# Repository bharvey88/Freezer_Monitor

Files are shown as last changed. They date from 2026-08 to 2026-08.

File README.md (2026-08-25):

# Freezer Monitor

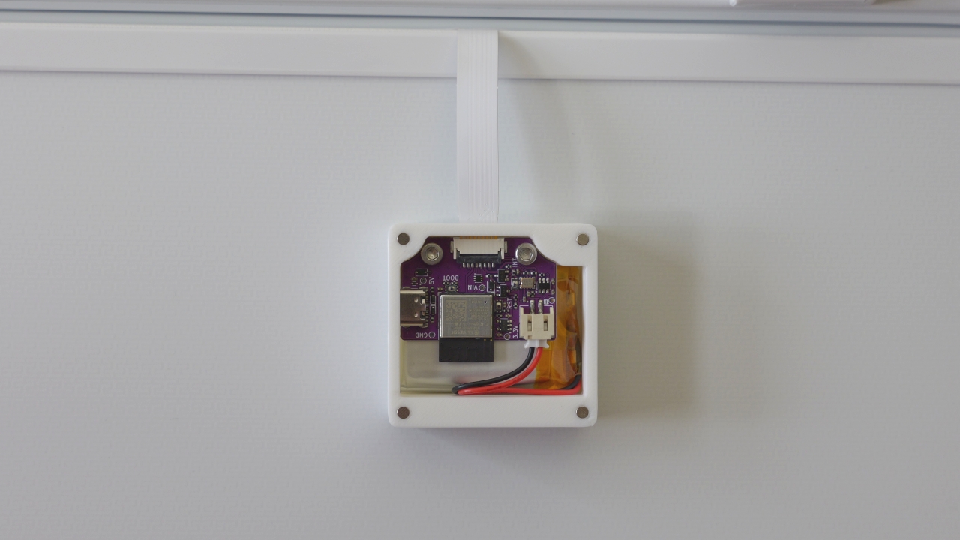
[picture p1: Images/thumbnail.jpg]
thumbnail


Battery-powered freezer monitor for Home Assistant and ESPHome. It continuously watches freezer temperature using a flat printed circuit sensor probe, wakes Home Assistant immediately for high-temperature events, and uses RTC-controlled power cycling for long battery life.

Setup Video: https://youtu.be/nzpPNruYSMk

Technical Video: https://youtu.be/-qzcmOnRHUw

Setting up Helpers and Notifcations: https://youtu.be/nKuBQElTua8

Etsy (purchase): https://www.etsy.com/listing/4555225886/freezer-monitor-for-home-assistant

## Contents

- [Requirements](#requirements)
- [Assemble and charge](#assemble-and-charge)
  - [Replacement battery safety](#replacement-battery-safety)
- [First-time setup](#first-time-setup)
- [How it works](#how-it-works)
  - [Optional persistent Keep Awake helper](#optional-persistent-keep-awake-helper)
- [Device controls and readings](#device-controls-and-readings)
- [Alerts and notifications](#alerts-and-notifications)
  - [Create a phone push or email alert](#create-a-phone-push-or-email-alert)
  - [Optional alert blueprint](#optional-alert-blueprint)
- [Updating and advanced ESPHome use](#updating-and-advanced-esphome-use)
  - [Manual USB flashing](#manual-usb-flashing)
- [Errata](#errata)
- [Project files](#project-files)
- [Troubleshooting](#troubleshooting)

## Requirements

- Home Assistant with the ESPHome add-on or integration installed.
- A 2.4 GHz Wi-Fi network.
- The supplied pre-flashed Freezer Monitor, FPC probe, and battery.
- Optional: Home Assistant Companion App for phone push notifications, or an existing Home Assistant email notification service for email alerts.

## Assemble and charge

1. Connect the temperature probe.
2. Connect the supplied battery.
3. Charge the battery through the USB port.
4. Continue with first-time setup below.

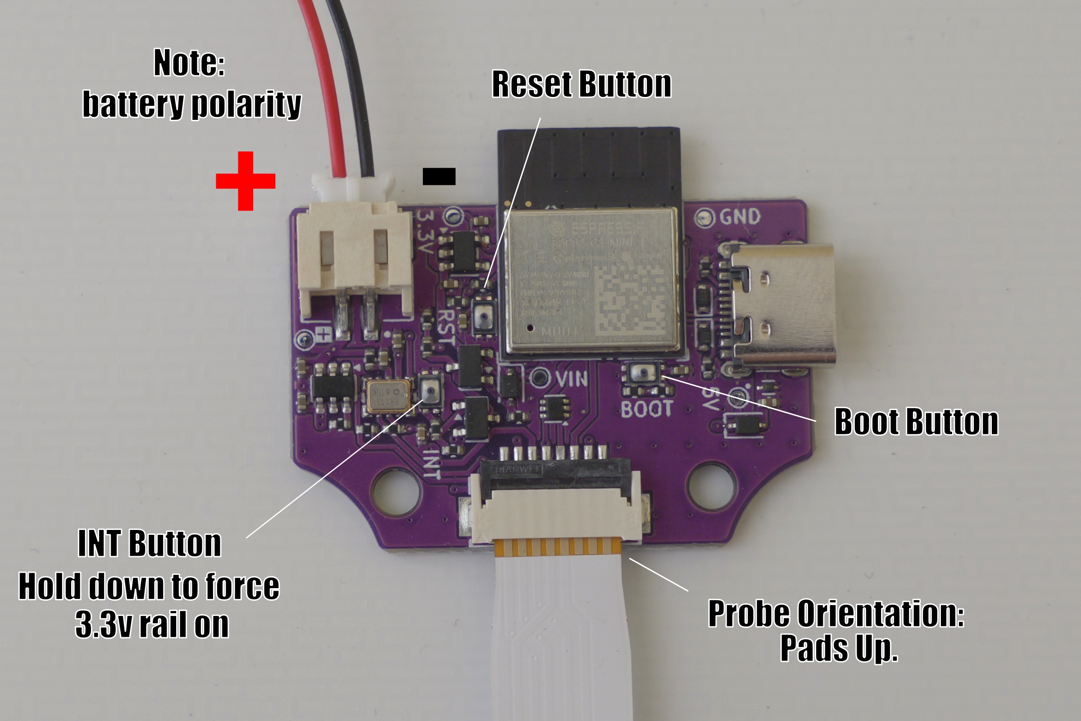
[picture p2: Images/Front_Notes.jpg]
Front view showing probe connection


### Replacement battery safety

Use only a single-cell 3.7 V LiPo battery with a PH-style connector. Verify connector polarity before connecting a replacement battery. Reversed polarity can permanently damage the PCB.

## First-time setup

1. Power the freezer monitor via USB. It stays awake by default for configuration.
2. Provision Wi-Fi using either Bluetooth Improv or the `Freezer Monitor Setup` captive portal. Provisioning has a ten minute timeout. Power cycle the device to reopen the provisioning window if it expires. The fallback `Freezer Monitor Setup` Wi-Fi network is unsecured. Complete provisioning promptly and configure one unprovisioned monitor at a time.
3. Finish Home Assistant discovery and setup by going to **Settings → Devices & services** and adding the freezer monitor. Home Assistant assigns the device API encryption key during this process.
4. Go into the device settings and set alert thresholds and heartbeat schedule if desired.
5. Unplug from USB power and turn off **Keep On for Configuration** in the device controls. Normal low-power monitoring starts after the current wake period. Note: without an initial valid RTC time sync, normal shutdown cycles cannot start, and the device will not power itself off. Once an initial time sync happens, the RTC can maintain time even if it cannot sync every power cycle (such as when wifi is down), so this is only an issue at initial setup.

## How it works

The probe-side TMP102 sensor monitors freezer temperature continuously, even when the ESP32 is powered off. The RTC controls ESP32 power and records both scheduled wakes and temperature events.

| Term | Meaning |
| --- | --- |
| **Alarm** | A scheduled RTC heartbeat wake. Default: every 12 hours. |
| **Event / Alert** | A freezer temperature above **High Temp Threshold**. This wakes the ESP32 immediately. |
| | |

During a normal Alarm wake, the monitor powers on for about 12 seconds, updates Home Assistant with freezer and ambient temperature, battery voltage/percentage, Wi-Fi signal, and wake status, then the RTC cuts ESP32 power again.

The default heartbeat schedule is every 12 hours. **Wake Start Hour (UTC)** and **Wake Start Minute** determine the base heartbeat time; **Wake Interval Hours** selects interval length in between heartbeats. Wake times for the device are then derived from the selected time and interval settings. All schedule times are UTC. Adjust them manually when local-time or daylight-saving changes require it. Setting wake interval to 0 will wake the device once a day (every 24hrs).

The monitor must be awake and connected to Wi-Fi before Home Assistant can update the device settings. Normal wake windows are brief; enable **Keep On for Configuration** while making several changes, updating firmware, or adopting the device.

### Optional persistent Keep Awake helper

The device control **Keep On for Configuration** always remains available and works while the monitor is awake. For an optional control that remembers a request made while the monitor is powered off, create a Home Assistant **Toggle** helper named `Freezer Monitor Keep Awake`. Its entity ID must be `input_boolean.freezer_monitor_keep_awake`.

Use **Settings → Devices & services → Helpers → Create helper → Toggle**. The helper state is stored by Home Assistant. On the monitor's next successful connection to Home Assistant, its saved state is applied: on keeps the monitor awake; off resumes normal RTC power cycling. Using the device's existing **Keep On for Configuration** control also updates the helper when it exists.

You will also need to allow the device to perform actions for the helper to function. Navigate to **Settings → Devices & services → ESPHome** and find the device in the list. Click on the gear to access the options, and check the box for **Allow the device to perform Home Assistant actions.**

The helper cannot power on the monitor immediately and cannot apply its value during a wake where the monitor cannot connect to Home Assistant. Users who do not create the helper can continue using the device control normally during an awake period.

## Device controls and readings

| Home Assistant entity | Purpose |
| --- | --- |
| **CONTROLS**| |
| **Acknowledge Freezer Alarm** | Acknowledges a temperature event so normal power cycling can resume. |
| **Clear Temp Threshold** | Temperature the freezer must fall below before an alert can clear. Default: 9 °F. |
| **High Temp Threshold** | Temperature that triggers an Event/Alert. Default: 10 °F. |
|||
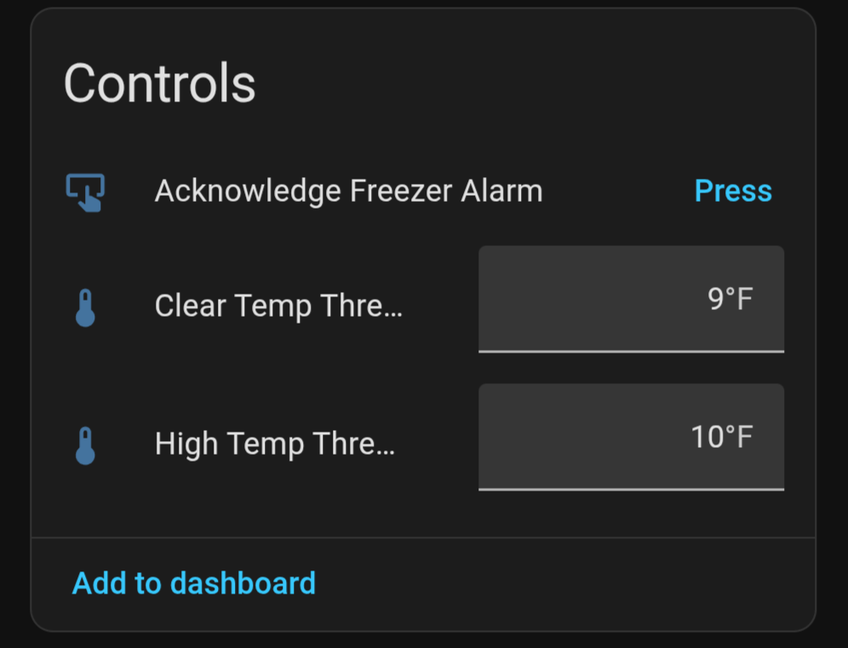
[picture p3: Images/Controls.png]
App Controls


| Home Assistant entity | Purpose |
| --- | --- |
| **SENSORS**| |
| **Ambient** | Temperature at the main device PCB. This will not be accurate if the device is on for more than a brief time, as the ESP32 and other circuitry will rapidly heat the enclosure above true ambient temperatures. |
| **Battery Percentage** / **Battery Voltage** | Battery condition reported during an awake period. Percentage is an estimate from the configured LiPo voltage curve. Consider this approximate rather than precise. |
| **Freezer Temperature** | Temperature at the end of the probe. |
| **High Temp Alert** | On while the probe sensor reports a high-temperature condition. |
| **Last Wake Reason** / **Last Wake Time** | Last RTC wake cause and time. |
| **Threshold Status** | Reports threshold write or validation status. |
|||
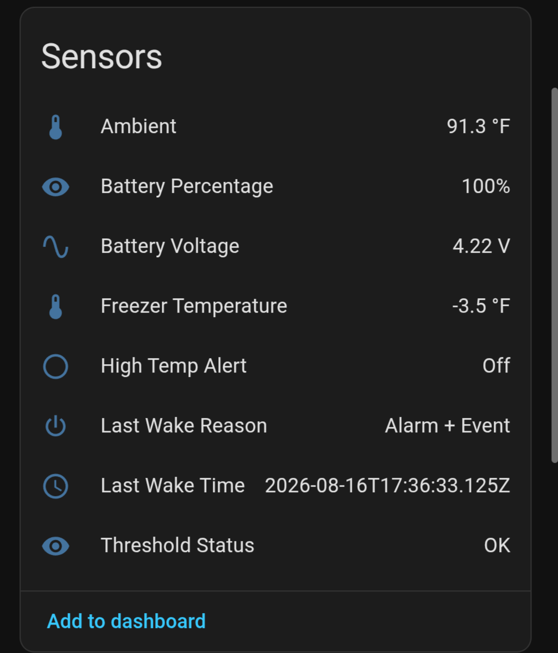
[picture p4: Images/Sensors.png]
App Sensors


| Home Assistant entity | Purpose |
| --- | --- |
| **CONFIGURATION**| |
| **Keep On for Configuration** | Keeps the monitor powered for setup, updates, and configuration. Turn it off for normal low-power operation. |
| **Wake Start Hour (UTC)** / **Wake Start Minute** / **Wake Interval Hours** | Heartbeat schedule controls. |
|  |  |
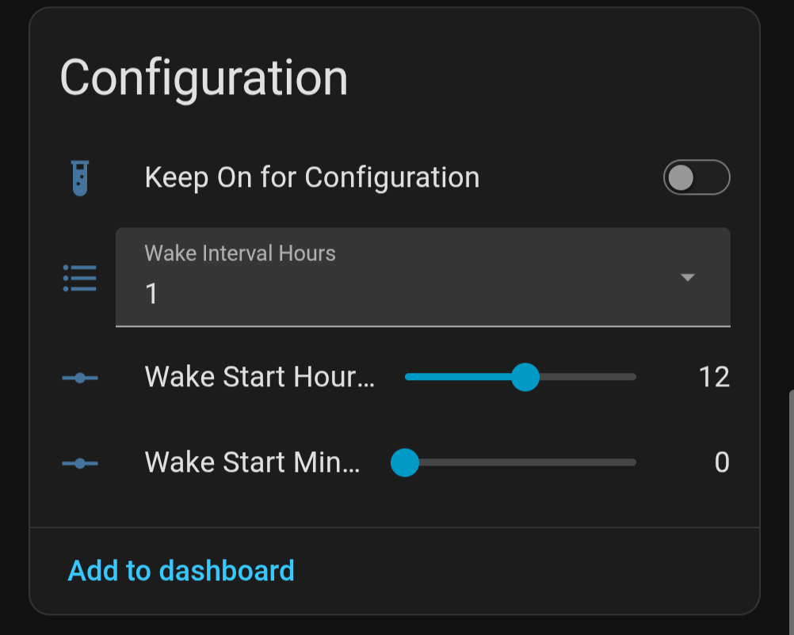
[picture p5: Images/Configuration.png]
App Configuration


Home Assistant presents temperature sensors and threshold controls in its configured preferred temperature unit. Firmware defaults are 10 °F high and 9 °F clear; the device stores the underlying TMP102 limits in Celsius.

The clear threshold must be lower than the high threshold. The device rejects a high threshold below the clear threshold, or a clear threshold above the high threshold.

## Alerts and notifications

When freezer temperature rises above **High Temp Threshold**, the probe signals the RTC. The RTC creates an Event, turns on the ESP32, and Home Assistant receives the **High Temp Alert** state.

The monitor remains powered after an alert until both conditions are true:

1. Freezer temperature has fallen below **Clear Temp Threshold**.
2. You press **Acknowledge Freezer Alarm** in Home Assistant.

The monitor reports alert state to Home Assistant; it does not directly send push notifications or email. Create a Home Assistant automation to deliver notifications.

### Create a phone push or email alert

1. In Home Assistant, open **Settings → Automations & Scenes → Create Automation**.
2. Create a new empty automation and add a **State** trigger.
3. Select this monitor **High Temp Alert** entity and set **To** to `on`.
4. For a phone notification, add the following action in the automation YAML editor. Replace `notify.mobile_app_your_phone` with your phone's Home Assistant Companion App notification service. Tapping the notification opens the triggering entity; **View Sensor** adds an explicit action button.

```yaml
- action: notify.mobile_app_your_phone
  data:
    title: "Freezer temperature alert"
    message: "Check the freezer monitor."
    data:
      # Keep only the line for your phone's OS; remove the other.
      # Android notification tap target:
      clickAction: "entityId:{{ trigger.entity_id }}"
      # iPhone/iPad notification tap target:
      url: "entityId:{{ trigger.entity_id }}"
      actions:
        - action: URI
          title: View Sensor
          uri: "entityId:{{ trigger.entity_id }}"
```

5. For email instead, add your already configured Home Assistant email notification service and a title/message such as `Freezer temperature alert` and `Check the freezer monitor.`
6. Save the automation.

Optional: create a second automation triggered when **High Temp Alert** changes to `off` to send a recovery notification.

### Optional alert blueprint

As an alternative to building the automations above by hand, the **Freezer Monitor Alerts** blueprint builds them for you. It sends the high temperature alert, repeats it until the freezer recovers, sends a recovery message, and can press **Acknowledge Freezer Alarm** on your behalf, so a monitor that has finished setup resumes power cycling on its own. Low battery and missed heartbeat alerts are included and are off by default.



1. Click the badge above. If it does not open, copy `https://github.com/techdregs/Freezer_Monitor/blob/main/Blueprints/freezer_monitor_alerts.yaml` into **Settings → Automations & Scenes → Blueprints → Import Blueprint**.
2. Click **Create Automation** on the imported blueprint.
3. Pick your Freezer Monitor from the device dropdown. The blueprint finds the entities it needs by itself. If you have renamed the monitor's entity IDs, open **Manual entity overrides** and pick them by hand.
4. Under **When the freezer is too warm**, replace the default Home Assistant notification with your Companion App notify action for phone push, or your configured email notify action. The phone notification action shown above works here too.
5. Save.

The blueprint re-sends the alert every 15 minutes until the freezer drops below **Clear Temp Threshold**. Set the repeat interval to 0 to alert only once.

To turn on the extra alerts, open the collapsed sections and raise their thresholds above 0. **Low battery alert** fires when Battery Percentage drops below the value you pick. **Missed heartbeat alert** fires when **Last Wake Time** has not changed for longer than you allow, which catches a flat battery, a Wi-Fi outage, or a monitor that has stopped waking. Set it comfortably longer than your **Wake Interval Hours**, for example 26 hours on the default 12 hour heartbeat. Restarting Home Assistant restarts that clock.

## Updating and advanced ESPHome use

The pre-flashed firmware is intended to work without YAML edits. Advanced ESPHome users can adopt the device from the ESPHome dashboard:

1. Wait for the device to wake, then enable **Keep On for Configuration**.
2. Use ESPHome dashboard adoption. The dashboard import downloads the full local YAML configuration.
3. Edit or update as needed, then compile and install firmware.
4. Turn off **Keep On for Configuration** to resume low-power operation.

Compiling the adopted YAML requires Internet access from the ESPHome host. It downloads the external TMP102 and RX8XXX ESPHome components referenced in the configuration.

Serial logs are disabled in the shipped firmware (`logger.baud_rate: 0`) to reduce power use.

### Manual USB flashing

Use manual flashing only to recover a device or install the supplied precompiled firmware. This can be done with either ESPHome Web or esptool. Keep the monitor connected to USB power throughout this process. Erasing flash removes all saved Wi-Fi credentials, the API encryption key, and device settings; complete first-time setup again afterward.

#### with ESPHome Web

No local ESPHome or `esptool` installation is required. In Chrome, Edge, or another browser with Web Serial support, open [ESPHome Web](https://web.esphome.io/), connect the monitor's USB serial port, select **Install**, then select [the factory firmware](Firmware/freezer-monitor-firmware.factory.0.1.1.bin).

#### with esptool via command line

Install `esptool` first. With Python installed, run:

```bash
python3 -m pip install --user esptool
```

Then erase and flash the device. Replace `/dev/ttyACM0` with its serial port, such as `COM3` on Windows:

```bash
esptool --chip esp32c3 --port /dev/ttyACM0 erase-flash
esptool --chip esp32c3 --port /dev/ttyACM0 write-flash 0x0 Firmware/freezer-monitor-firmware.factory.0.1.1.bin
```

## Errata

There is a silkscreen error on the back of the PCB for the probe pins. This will not affect the device use unless you wish to make your own probe.

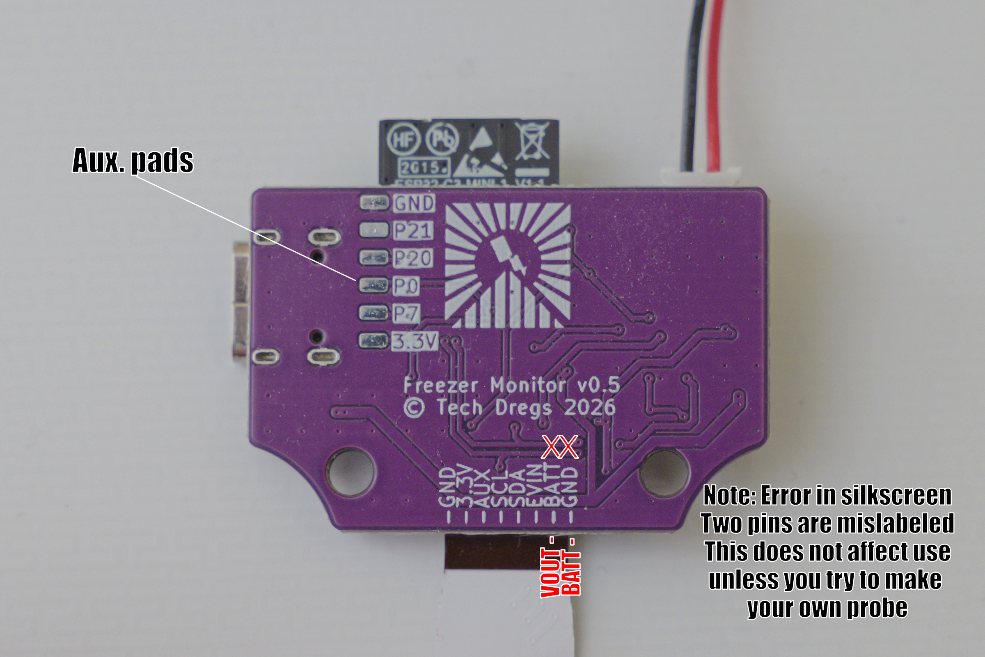
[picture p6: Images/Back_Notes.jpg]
Back view


## Project files

- [ESPHome YAML](YAML/Freezer_Monitor.yaml)
- [Freezer Monitor Alerts blueprint](Blueprints/freezer_monitor_alerts.yaml)
- [Precompiled factory firmware 0.1.1](Firmware/freezer-monitor-firmware.factory.0.1.1.bin)
- Schematics: [main PCB](Schematics/Freezer%20Monitor%200.5.pdf), [flat probe cable](Schematics/Flat_NTC.pdf), and [KiCad FPC footprint](Schematics/FPC_Footprint/FPC8_1.0mm.kicad_mod)
- Datasheets: [ESP32-C3-MINI-1](Datasheets/esp32-c3-mini-1_datasheet_en.pdf), [RX8111CE RTC](Datasheets/RX8111CE_en.pdf), and [TMP102](Datasheets/TMP102_UMW.pdf)
- Enclosure models: [housing](Enclosure/Freezer%20Monitor%20v0.5%20Enclosure-Housing.3mf), [lid](Enclosure/Freezer%20Monitor%20v0.5%20Enclosure-Lid.3mf), and [complete enclosure STEP](Enclosure/Freezer%20Monitor%20v0.5%20Enclosure.step)
- PCB/probe models: [PCB STEP](PCB%20Models/Freezer%20Monitor%20PCB%20v0.5.step) and [flat probe STEP](PCB%20Models/Flat_Probe.step)

Schematics and models are supplied for reference and custom enclosure design. 

## Troubleshooting

| Problem | Check |
| --- | --- |
| Device remains on after disabling Keep On | Confirm it has received Home Assistant time synchronization. The monitor cannot schedule its first normal power cut until RTC time is valid. |
| A setting does not change | The monitor was likely powered off. Wait for an awake period or enable **Keep On for Configuration**. |
| No phone/email alert | Confirm **High Temp Alert** changes to `on` and that the Home Assistant automation and notification service work. |
| Cannot use serial logs | Shipped firmware intentionally disables serial logging. Use ESPHome logs/API while the device is awake, or customize YAML after adoption. |

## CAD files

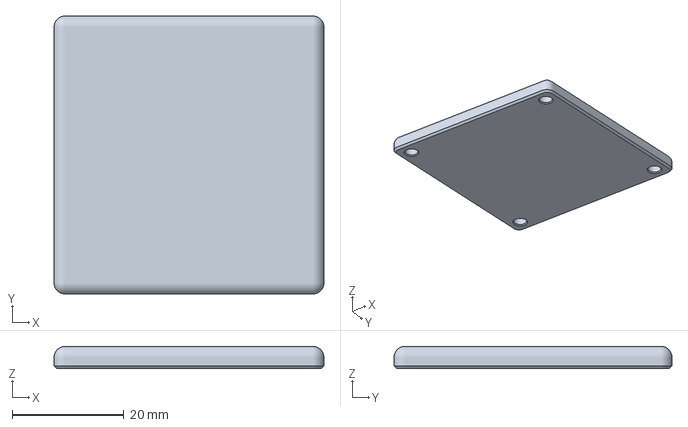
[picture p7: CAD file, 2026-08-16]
Enclosure/Freezer Monitor v0.5 Enclosure-Lid.3mf
48.4 x 49.8 x 4.00 mm

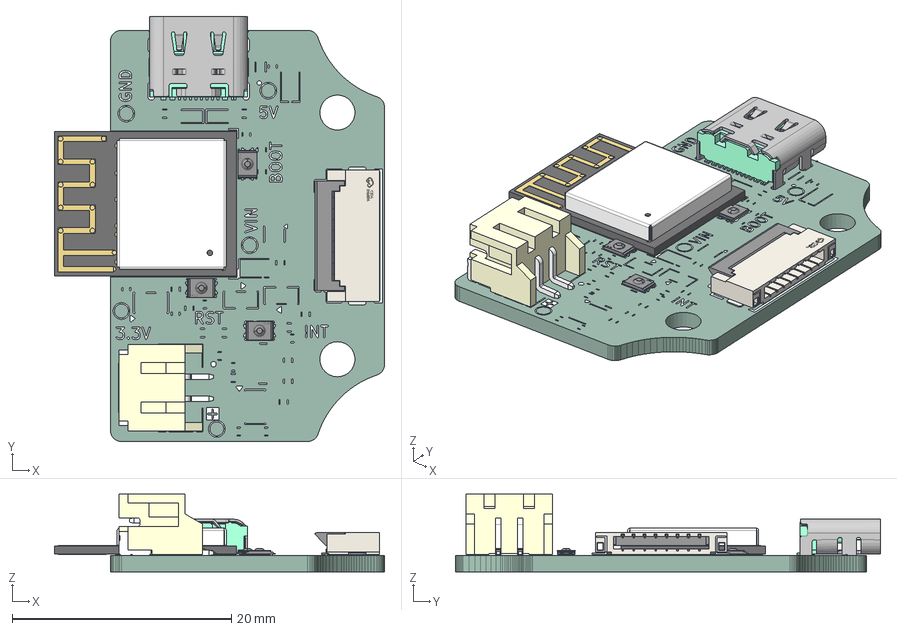
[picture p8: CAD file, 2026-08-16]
PCB Models/Freezer Monitor PCB v0.5.step
30.1 x 38.8 x 7.17 mm
SW-SMD_4P-L2.5-W1.6-LS2.9_STI-055A12AX x 6
DFN1006.STEP^DFN1006.STEP_Submodel-SOD882_part_DesignRootModel_PCB_ ESP32-C3-MINI-1_V1(2)_PCB_ESP32-C3-MINI-1_V1
R0201_20210301.STEP^R0201_20210301.STEP_Submodel-R0201_part_ DesignRootModel_PCB_ESP32-C3-MINI-1_V1(2)_PCB_ESP32-C3-MINI-1_V1 x 3
placementOutline^Submodel-noModelForPart_MINI-ANT-TYPED-H_1968823293_ Submodel-MINI-ANT-TYPED-H_1968823293_part_DesignRootModel_PCB_ ESP32-C3-MINI-1_V1(2)_PCB_E
placementOutline-0^Submodel-noModelForPart_MINI-ANT-TYPED-H_1968823293_ Submodel-MINI-ANT-TYPED-H_1968823293_part_DesignRootModel_PCB_ ESP32-C3-MINI-1_V1(2)_PCB
placementOutline-1^Submodel-noModelForPart_MINI-ANT-TYPED-H_1968823293_ Submodel-MINI-ANT-TYPED-H_1968823293_part_DesignRootModel_PCB_ ESP32-C3-MINI-1_V1(2)_PCB
placementOutline-2^Submodel-noModelForPart_MINI-ANT-TYPED-H_1968823293_ Submodel-MINI-ANT-TYPED-H_1968823293_part_DesignRootModel_PCB_ ESP32-C3-MINI-1_V1(2)_PCB
placementOutline-3^Submodel-noModelForPart_MINI-ANT-TYPED-H_1968823293_ Submodel-MINI-ANT-TYPED-H_1968823293_part_DesignRootModel_PCB_ ESP32-C3-MINI-1_V1(2)_PCB
placementOutline-4^Submodel-noModelForPart_MINI-ANT-TYPED-H_1968823293_ Submodel-MINI-ANT-TYPED-H_1968823293_part_DesignRootModel_PCB_ ESP32-C3-MINI-1_V1(2)_PCB
placementOutline-5^Submodel-noModelForPart_MINI-ANT-TYPED-H_1968823293_ Submodel-MINI-ANT-TYPED-H_1968823293_part_DesignRootModel_PCB_ ESP32-C3-MINI-1_V1(2)_PCB
trace_4^Submodel-MINI-ANT-TYPED-H_1968823293_part_DesignRootModel_PCB_ ESP32-C3-MINI-1_V1(2)_PCB_ESP32-C3-MINI-1_V1
trace_1^Submodel-MINI-ANT-TYPED-H_1968823293_part_DesignRootModel_PCB_ ESP32-C3-MINI-1_V1(2)_PCB_ESP32-C3-MINI-1_V1
C0402_20210301.STEP^C0402_20210301.STEP_Submodel-C0402_part_ DesignRootModel_PCB_ESP32-C3-MINI-1_V1(2)_PCB_ESP32-C3-MINI-1_V1
C0201_20210301.STEP^C0201_20210301.STEP_Submodel-C0201_part_ DesignRootModel_PCB_ESP32-C3-MINI-1_V1(2)_PCB_ESP32-C3-MINI-1_V1 x 11
L0201_20210301.STEP^L0201_20210301.STEP_Submodel-L0201_part_ DesignRootModel_PCB_ESP32-C3-MINI-1_V1(2)_PCB_ESP32-C3-MINI-1_V1 x 2
XTAL3225_20210301.STEP^XTAL3225_20210301.STEP_Submodel-XTAL3225_part_ DesignRootModel_PCB_ESP32-C3-MINI-1_V1(2)_PCB_ESP32-C3-MINI-1_V1
ESP32-C3_20210301.STEP^ESP32-C3_20210301.STEP_Submodel-QFN32_0P5_5_ part_DesignRootModel_PCB_ESP32-C3-MINI-1_V1(2)_PCB_ESP32-C3-MINI-1_V1
uid__4^DesignRootModel_PCB_ESP32-C3-MINI-1_V1(2)_PCB_ESP32-C3-MINI-1_ V1
uid__4-22^DesignRootModel_PCB_ESP32-C3-MINI-1_V1(2)_PCB_ ESP32-C3-MINI-1_V1
uid__4-23^DesignRootModel_PCB_ESP32-C3-MINI-1_V1(2)_PCB_ ESP32-C3-MINI-1_V1
uid__4-24^DesignRootModel_PCB_ESP32-C3-MINI-1_V1(2)_PCB_ ESP32-C3-MINI-1_V1
uid__4-25^DesignRootModel_PCB_ESP32-C3-MINI-1_V1(2)_PCB_ ESP32-C3-MINI-1_V1
uid__4-26^DesignRootModel_PCB_ESP32-C3-MINI-1_V1(2)_PCB_ ESP32-C3-MINI-1_V1
uid__4-27^DesignRootModel_PCB_ESP32-C3-MINI-1_V1(2)_PCB_ ESP32-C3-MINI-1_V1
uid__4-28^DesignRootModel_PCB_ESP32-C3-MINI-1_V1(2)_PCB_ ESP32-C3-MINI-1_V1
uid__4-29^DesignRootModel_PCB_ESP32-C3-MINI-1_V1(2)_PCB_ ESP32-C3-MINI-1_V1
uid__4-30^DesignRootModel_PCB_ESP32-C3-MINI-1_V1(2)_PCB_ ESP32-C3-MINI-1_V1
uid__4-31^DesignRootModel_PCB_ESP32-C3-MINI-1_V1(2)_PCB_ ESP32-C3-MINI-1_V1
uid__4-32^DesignRootModel_PCB_ESP32-C3-MINI-1_V1(2)_PCB_ ESP32-C3-MINI-1_V1
uid__4-33^DesignRootModel_PCB_ESP32-C3-MINI-1_V1(2)_PCB_ ESP32-C3-MINI-1_V1
uid__4-34^DesignRootModel_PCB_ESP32-C3-MINI-1_V1(2)_PCB_ ESP32-C3-MINI-1_V1
uid__4-35^DesignRootModel_PCB_ESP32-C3-MINI-1_V1(2)_PCB_ ESP32-C3-MINI-1_V1
uid__4-36^DesignRootModel_PCB_ESP32-C3-MINI-1_V1(2)_PCB_ ESP32-C3-MINI-1_V1
uid__4-37^DesignRootModel_PCB_ESP32-C3-MINI-1_V1(2)_PCB_ ESP32-C3-MINI-1_V1
uid__4-38^DesignRootModel_PCB_ESP32-C3-MINI-1_V1(2)_PCB_ ESP32-C3-MINI-1_V1
uid__4-39^DesignRootModel_PCB_ESP32-C3-MINI-1_V1(2)_PCB_ ESP32-C3-MINI-1_V1
uid__4-40^DesignRootModel_PCB_ESP32-C3-MINI-1_V1(2)_PCB_ ESP32-C3-MINI-1_V1
uid__4-41^DesignRootModel_PCB_ESP32-C3-MINI-1_V1(2)_PCB_ ESP32-C3-MINI-1_V1
uid__4-42^DesignRootModel_PCB_ESP32-C3-MINI-1_V1(2)_PCB_ ESP32-C3-MINI-1_V1
uid__4-43^DesignRootModel_PCB_ESP32-C3-MINI-1_V1(2)_PCB_ ESP32-C3-MINI-1_V1
uid__4-44^DesignRootModel_PCB_ESP32-C3-MINI-1_V1(2)_PCB_ ESP32-C3-MINI-1_V1
uid__4-45^DesignRootModel_PCB_ESP32-C3-MINI-1_V1(2)_PCB_ ESP32-C3-MINI-1_V1
uid__4-46^DesignRootModel_PCB_ESP32-C3-MINI-1_V1(2)_PCB_ ESP32-C3-MINI-1_V1
uid__4-47^DesignRootModel_PCB_ESP32-C3-MINI-1_V1(2)_PCB_ ESP32-C3-MINI-1_V1
uid__4-48^DesignRootModel_PCB_ESP32-C3-MINI-1_V1(2)_PCB_ ESP32-C3-MINI-1_V1
uid__4-49^DesignRootModel_PCB_ESP32-C3-MINI-1_V1(2)_PCB_ ESP32-C3-MINI-1_V1
uid__4-50^DesignRootModel_PCB_ESP32-C3-MINI-1_V1(2)_PCB_ ESP32-C3-MINI-1_V1
uid__4-51^DesignRootModel_PCB_ESP32-C3-MINI-1_V1(2)_PCB_ ESP32-C3-MINI-1_V1
uid__4-52^DesignRootModel_PCB_ESP32-C3-MINI-1_V1(2)_PCB_ ESP32-C3-MINI-1_V1
uid__4-53^DesignRootModel_PCB_ESP32-C3-MINI-1_V1(2)_PCB_ ESP32-C3-MINI-1_V1
uid__4-54^DesignRootModel_PCB_ESP32-C3-MINI-1_V1(2)_PCB_ ESP32-C3-MINI-1_V1
uid__4-55^DesignRootModel_PCB_ESP32-C3-MINI-1_V1(2)_PCB_ ESP32-C3-MINI-1_V1
uid__4-56^DesignRootModel_PCB_ESP32-C3-MINI-1_V1(2)_PCB_ ESP32-C3-MINI-1_V1
uid__4-57^DesignRootModel_PCB_ESP32-C3-MINI-1_V1(2)_PCB_ ESP32-C3-MINI-1_V1
uid__4-58^DesignRootModel_PCB_ESP32-C3-MINI-1_V1(2)_PCB_ ESP32-C3-MINI-1_V1
uid__4-59^DesignRootModel_PCB_ESP32-C3-MINI-1_V1(2)_PCB_ ESP32-C3-MINI-1_V1
uid__4-60^DesignRootModel_PCB_ESP32-C3-MINI-1_V1(2)_PCB_ ESP32-C3-MINI-1_V1
uid__4-61^DesignRootModel_PCB_ESP32-C3-MINI-1_V1(2)_PCB_ ESP32-C3-MINI-1_V1
uid__4-62^DesignRootModel_PCB_ESP32-C3-MINI-1_V1(2)_PCB_ ESP32-C3-MINI-1_V1
uid__4-63^DesignRootModel_PCB_ESP32-C3-MINI-1_V1(2)_PCB_ ESP32-C3-MINI-1_V1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

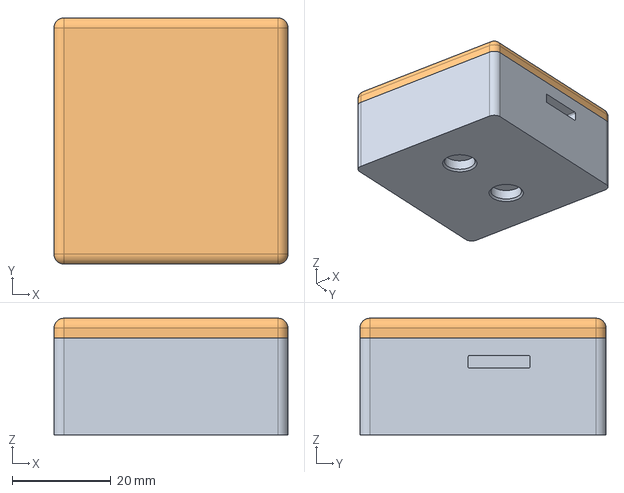
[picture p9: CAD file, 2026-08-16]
Enclosure/Freezer Monitor v0.5 Enclosure.step
47.4 x 49.8 x 23.6 mm
Housing
Lid

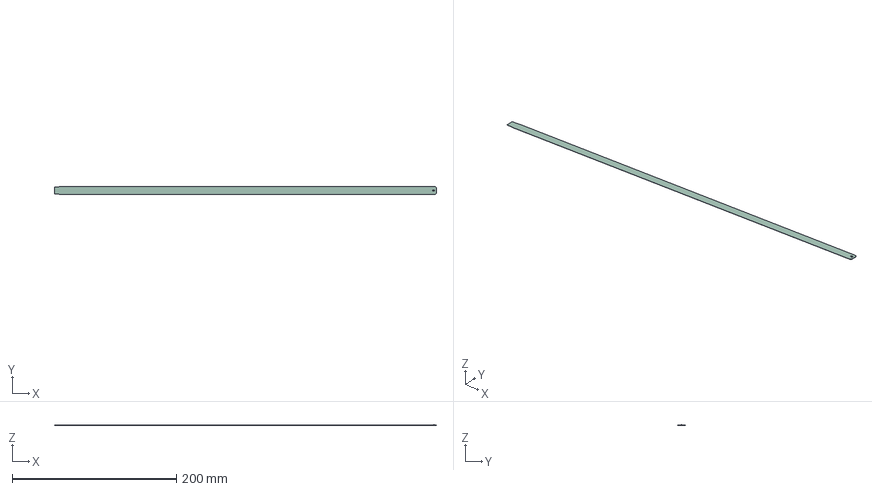
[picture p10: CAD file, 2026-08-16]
PCB Models/Flat_Probe.step
465.0 x 10.0 x 0.965 mm
SOT_563
R_0402_1005Metric
Flat_NTC_silkscreen
Flat_NTC_PCB

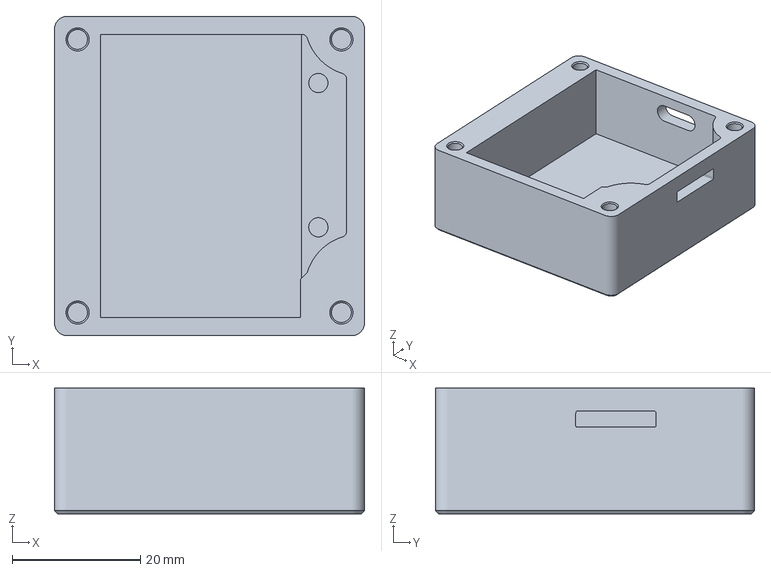
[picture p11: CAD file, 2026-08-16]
Enclosure/Freezer Monitor v0.5 Enclosure-Housing.3mf
48.4 x 49.8 x 19.6 mm

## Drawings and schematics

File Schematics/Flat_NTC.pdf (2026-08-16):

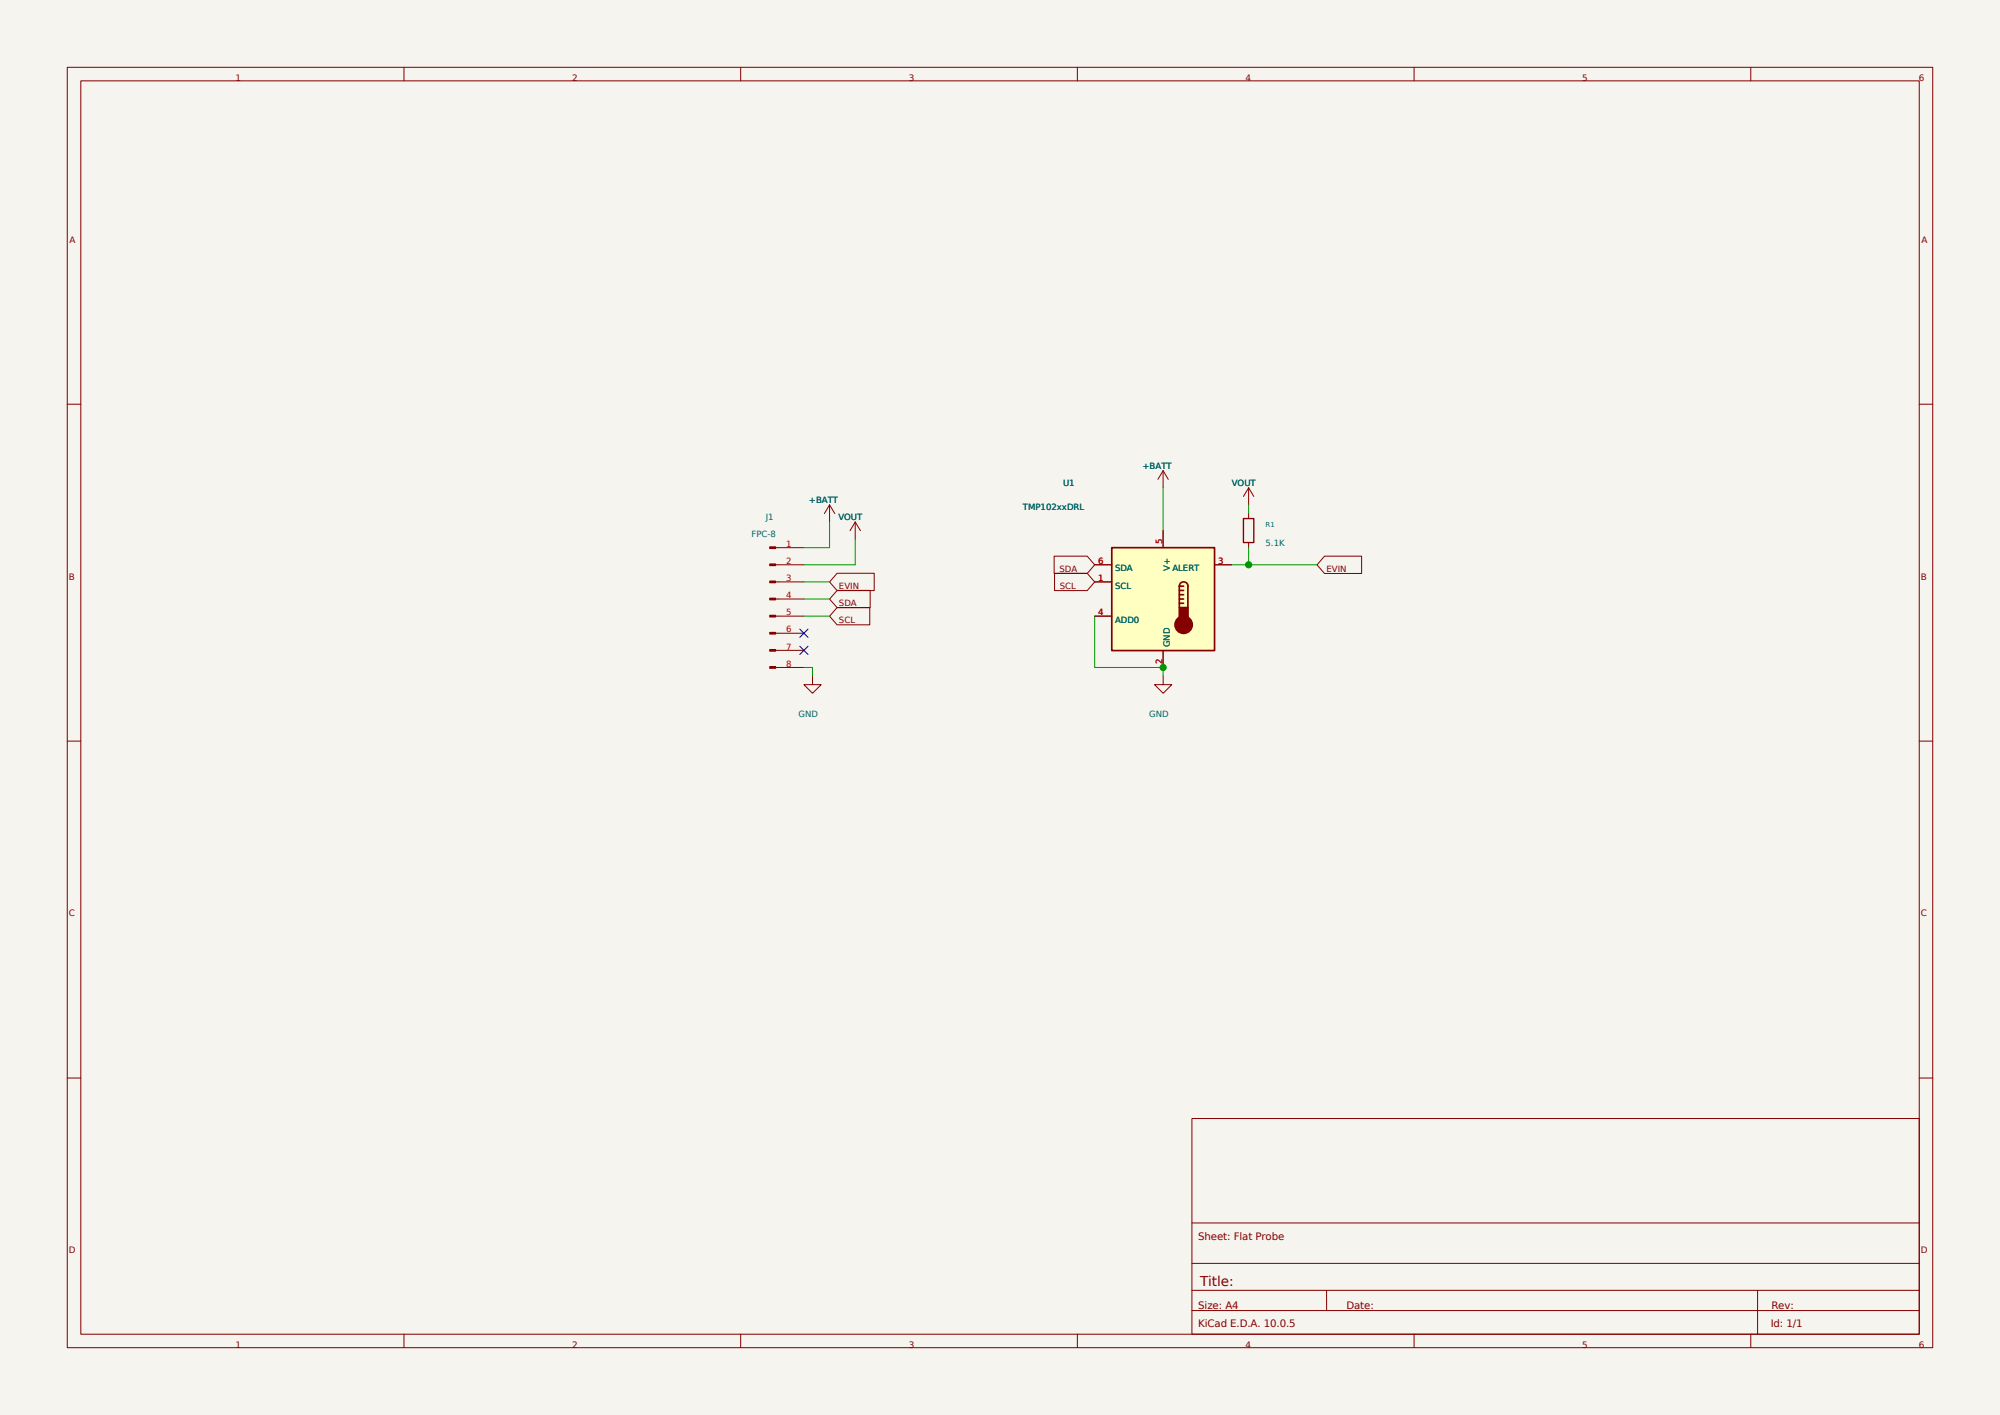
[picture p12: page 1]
Date:; KiCad E.D.A. 10.0.5; Size: A4; Rev:; Title:; FPC-8; +BATT; VOUT; GND; SCL; ALERT; ADD0; SDA; TMP102xxDRL; EVIN

Sheet: Flat Probe

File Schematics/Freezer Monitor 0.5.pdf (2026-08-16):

# ESP32-C3-MINI-1

# USB Jack

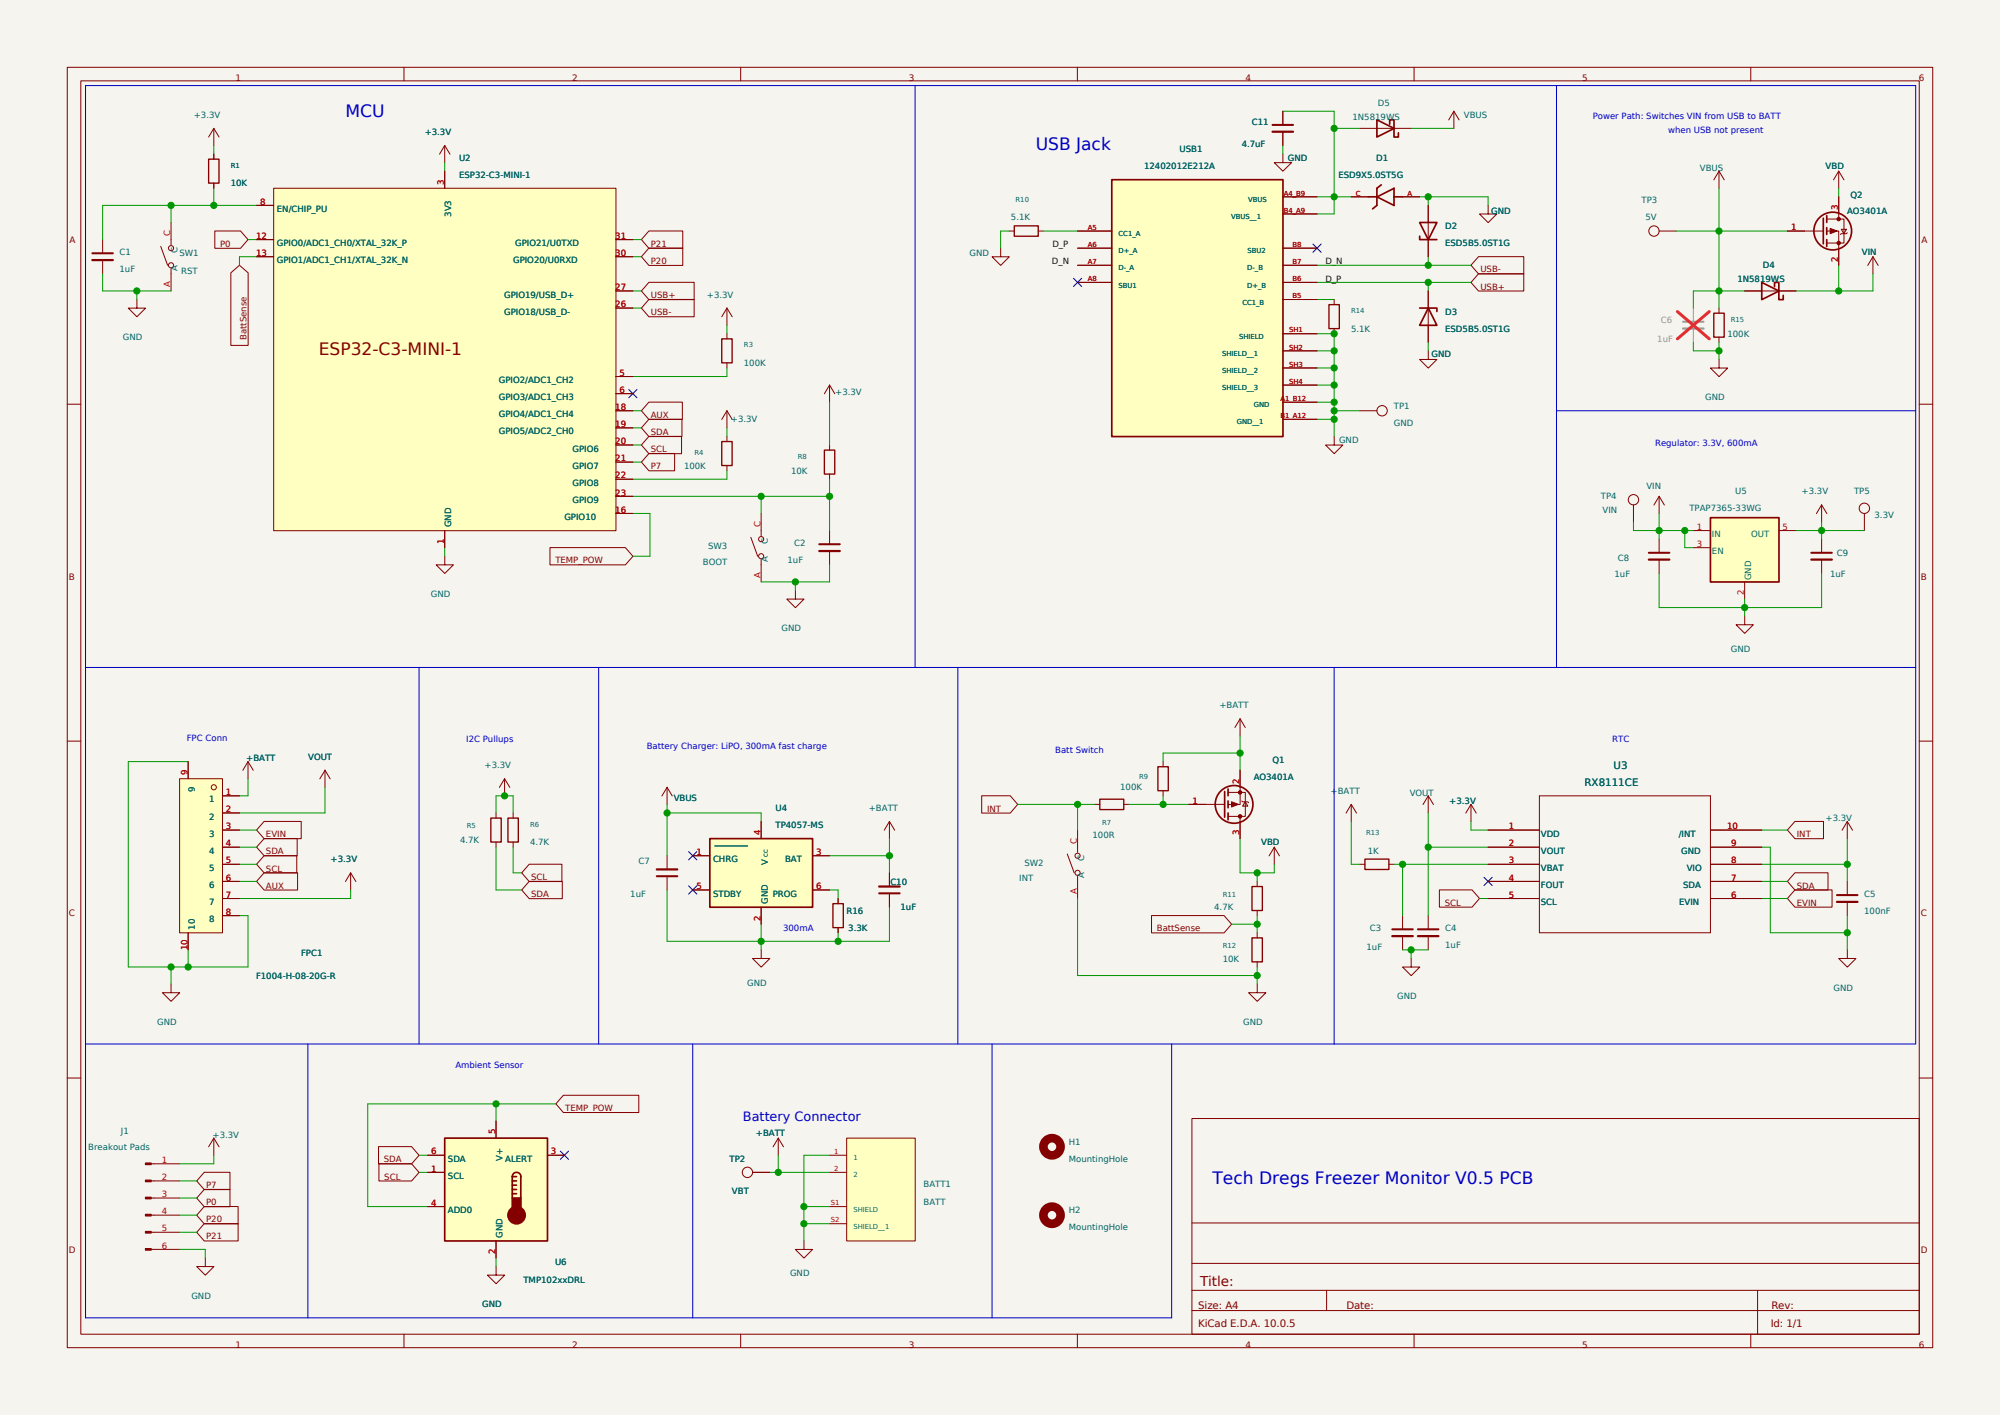
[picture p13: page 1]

Power Path: Switches VIN from USB to BATT

when USB not present

Battery Charger: LiPO, 300mA fast charge

Tech Dregs Freezer Monitor V0.5 PCB

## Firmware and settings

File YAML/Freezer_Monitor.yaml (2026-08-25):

substitutions:
  name: "freezer-monitor"
  friendly_name: "Freezer Monitor"
  
esphome:
  name: "${name}"
  friendly_name: "${friendly_name}"
  name_add_mac_suffix: true
  project:
    name: "techdregs.freezer-monitor"
    version: "0.1.3"
  on_boot:
    - priority: 500
      then:
        - switch.turn_on: tmp_power

esp32:
  variant: esp32c3
  cpu_frequency: 80MHZ
  framework:
    type: esp-idf

preferences:
  flash_write_interval: 1s

logger:
  id: logger_component
  level: WARN
  baud_rate: 0

api:
  id: api_server
  encryption: {}

provisioning:
  id: provisioning_component
  timeout: 10min

ota:
  - platform: esphome
    id: ota_esphome

dashboard_import:
  package_import_url: github://techdregs/Freezer_Monitor/YAML/Freezer_Monitor.yaml@main
  import_full_config: true

wifi:
  id: wifi_component
  fast_connect: True
  ap:
    ssid: "${friendly_name} Setup"

captive_portal:
  id: captive_portal_component

esp32_improv:
  id: improv_ble
  authorizer: none

safe_mode:
  id: safe_mode_component
  boot_is_good_after: 
    seconds: 10

globals:
  - id: cycle_fired
    type: bool
    restore_value: no
    initial_value: "false" 
  - id: woke_from_event
    type: bool
    restore_value: no
    initial_value: "false"
  - id: keep_on_for_testing
    type: bool
    restore_value: yes
    initial_value: "true"
  - id: next_alarm_hour
    type: uint16_t
    restore_value: no
    initial_value: "0"
  - id: next_alarm_minute
    type: uint16_t
    restore_value: no
    initial_value: "0"
  - id: next_alarm_valid
    type: bool
    restore_value: no
    initial_value: "false"

external_components:
  - source:
      type: git
      url: https://github.com/techdregs/TMP102_Extended
      ref: main
      path: .
    components: [tmp102_extended]
    refresh: always
    
  - source:
      type: git
      url: https://github.com/techdregs/RX8XXX
      ref: main
      path: ESPHome
    components: [rx8xxx]
    refresh: always

switch:
  - platform: gpio
    pin: GPIO10 #pin controls power to ambient TMP102 sensor only
    id: tmp_power
    internal: true
    restore_mode: ALWAYS_ON

  - platform: template
    id: keep_on_for_testing_switch
    name: "Keep On for Configuration"
    icon: mdi:test-tube
    entity_category: config
    restore_mode: disabled

    lambda: |-
      return id(keep_on_for_testing);

    turn_on_action:
      - globals.set:
          id: keep_on_for_testing
          value: "true"
      - logger.log: "Testing mode enabled: PMOS power cycle disabled"

      # If the optional HA helper exists and differs, keep it synchronized.
      - if:
          condition:
            lambda: |-
              return id(keep_awake_requested).has_state() &&
                     !id(keep_awake_requested).state;
          then:
            - homeassistant.action:
                action: input_boolean.turn_on
                data:
                  entity_id: input_boolean.freezer_monitor_keep_awake

    turn_off_action:
      - globals.set:
          id: keep_on_for_testing
          value: "false"
      - logger.log: "Testing mode disabled: normal PMOS cycling enabled"

      # If the optional HA helper exists and differs, keep it synchronized.
      - if:
          condition:
            lambda: |-
              return id(keep_awake_requested).has_state() &&
                     id(keep_awake_requested).state;
          then:
            - homeassistant.action:
                action: input_boolean.turn_off
                data:
                  entity_id: input_boolean.freezer_monitor_keep_awake

binary_sensor:
  # Optional persistent Keep Awake control. If the helper does not exist in HA,
  # this sensor has no state and the normal device switch remains independent.
  - platform: homeassistant
    id: keep_awake_requested
    entity_id: input_boolean.freezer_monitor_keep_awake
    internal: true
    trigger_on_initial_state: true
    on_state:
      then:
        - lambda: |-
            id(keep_on_for_testing) = x;

i2c:
  id: i2c_bus
  sda: GPIO5
  scl: GPIO6
  scan: true
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

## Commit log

2026-08-22 Add Freezer Monitor Alerts blueprint
    Replaces the hand-built notification automation in the README with an
    importable blueprint covering the high temp alert, repeat until recovery,
    the recovery message, optional auto-acknowledge, and optional low battery
    and missed heartbeat watchdogs.
2026-08-22 Fix alert reliability issues found in review
    Drop the from: state on the alert triggers so a high temperature event is
    still caught when the entity comes back from unavailable, which is what
    happens on every Home Assistant restart. Guard the recovery trigger with
    not_from so a restart does not press Acknowledge Freezer Alarm on its own.
    Replace the half-hourly heartbeat window with a state trigger using for:.
    The old arithmetic window fired only if a check landed inside a single
    30 minute band, so one missed poll meant a dead monitor was never reported.
    Home Assistant re-arms a for: trigger at startup.
    In the repeat loop, wait for recovery with a timeout instead of a bare
    delay, so the run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
2026-08-24 Fix initial "unavailable" states bug
    [Freezer_Monitor.yaml]
2026-08-24 Fixed edge case temp alert issue and phone notification action
    [Freezer_Monitor.yaml]
2026-08-25 Select the monitor as a device instead of five entities
    The blueprint now takes a single device picker, filtered to the
    techdregs freezer-monitor ESPHome project, and resolves the entities it
    needs from the device at load time by their default entity ID suffixes.
    A collapsed Manual entity overrides section covers renamed entities.
    The alert state triggers become a state_changed event trigger on the
    resolved entity, recovery now only fires off an actual on to off
    transition, and the battery and heartbeat checks move into template
    triggers. The heartbeat check also no longer needs a state change to
    start its timer, so a monitor that never checks in after a restart is
    still caught.
2026-08-25 Drop icon from the device input
    icon is only allowed on input sections, so import failed with an extra
    keys error on the device input.
2026-08-29 Debounce the low battery trigger
    The monitor publishes one bogus 0% reading on some wakes, before its
    battery voltage sensor has taken a reading, and Home Assistant retains it
    because the device declares deep_sleep. The float(101) guard only catches
    non-numeric states, so a numeric 0.0 fired the alert on a fully charged
    monitor.
    Hold the trigger for 5 minutes. The bogus reading clears in about 5
    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
